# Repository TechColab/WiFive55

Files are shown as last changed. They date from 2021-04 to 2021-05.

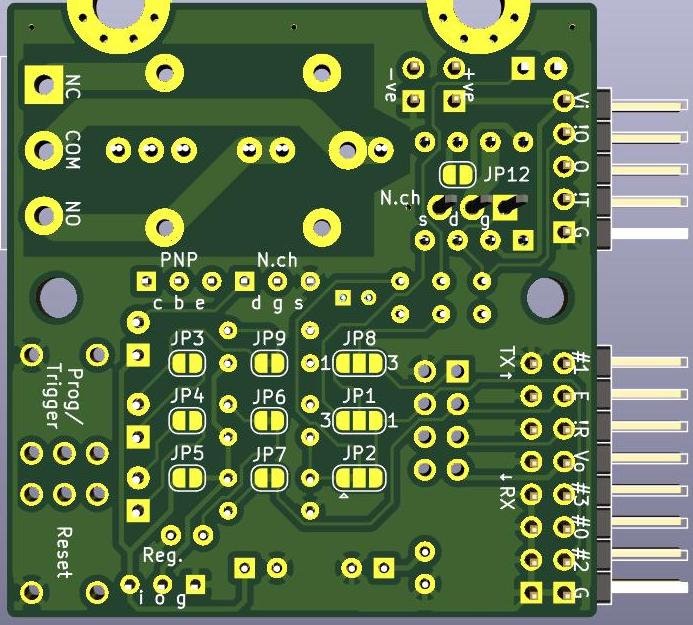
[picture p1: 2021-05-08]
KiCAD-THT/WiFive55-B.jpg

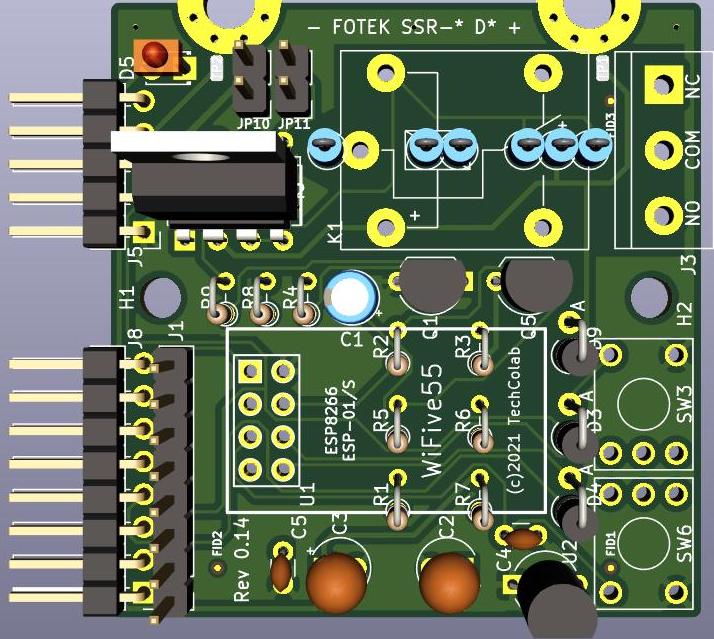
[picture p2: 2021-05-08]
KiCAD-THT/WiFive55-F.jpg

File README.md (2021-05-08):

# WiFive55

https://hackaday.io/project/178964-wifive55

.. or see the PDF

### 2021-05-03
Moved opto-isolator slightly to move relay footprints enough to accomodate longer but cheap & popular Omron G3MB-202P.  
Moved Through-Hole-Technology version to new folder to differentiate from Surface-Mount-Technology version to follow.

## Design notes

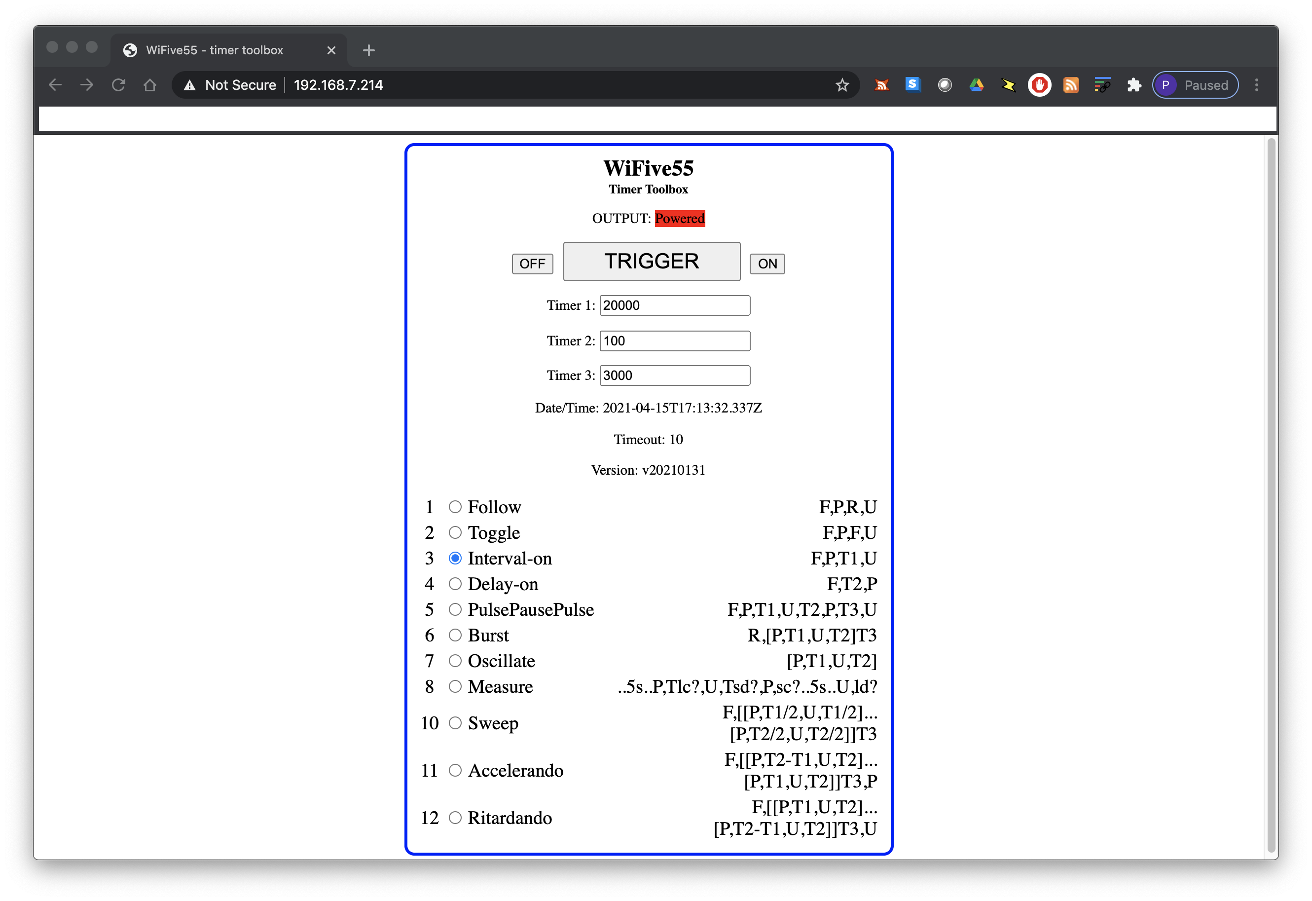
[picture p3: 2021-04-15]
Arduino/WiFive55-GUIalpha-running.png

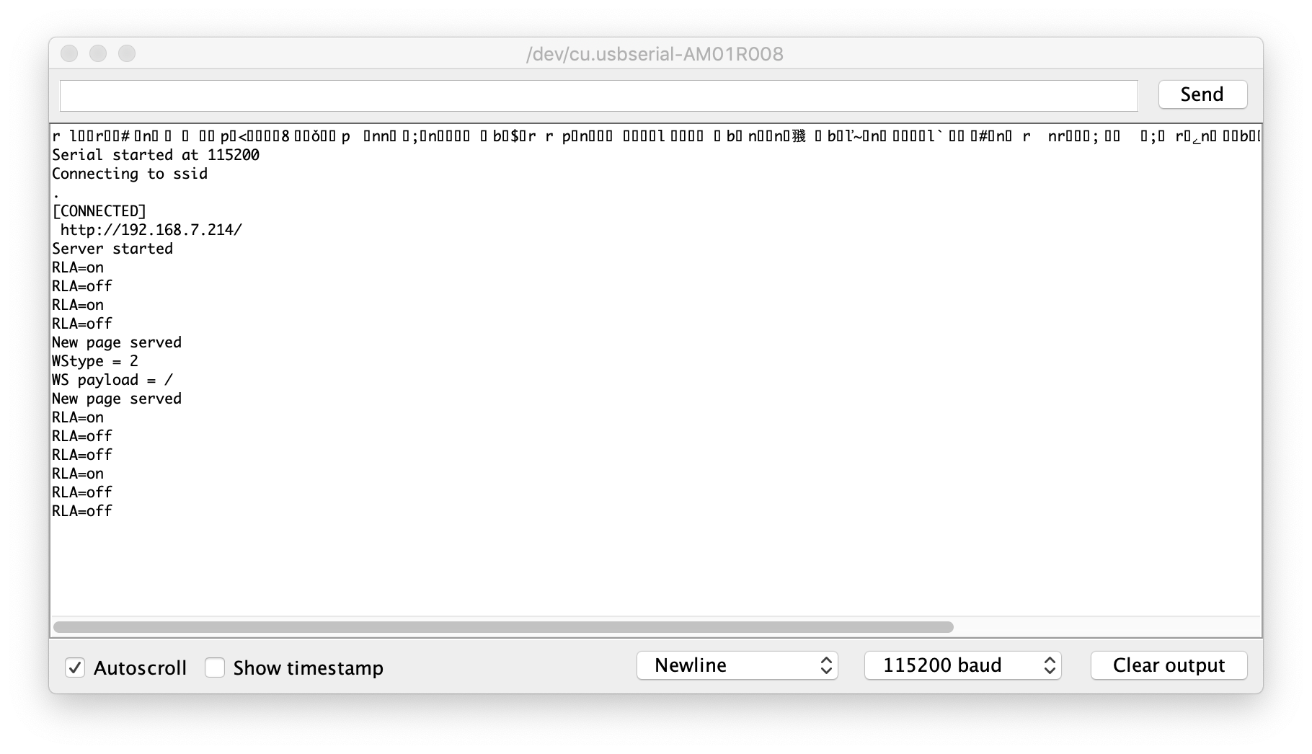
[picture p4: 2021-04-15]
Arduino/WiFive55-LOGalpha.png

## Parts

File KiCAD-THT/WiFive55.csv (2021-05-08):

Id | Designator | Package | Quantity | Designation | Supplier and ref
1 | , , , , , | TestPoint_Loop_D1.80mm_Drill1.0mm_Beaded | 6 | TestPoint_Loop_D1.80mm_Drill1.0mm_Beaded
2 | C3,C2 | CP_Radial_Tantal_D4.5mm_P2.50mm | 2 | 10
3 | C1 | CP_Radial_D4.0mm_P2.00mm | 1 | 4.7
4 | R4 | R_Axial_DIN0204_L3.6mm_D1.6mm_P2.54mm_Vertical | 1 | 200
5 | TP3 | MountingHole_4mm_Pad_Via | 1 | VIN+
6 | TP4 | MountingHole_4mm_Pad_Via | 1 | !OUT-
7 | TP2 | SolderWirePad_1x01_SMD_1x2mm | 1 | !OUT-
8 | TP1 | SolderWirePad_1x01_SMD_1x2mm | 1 | VIN+
9 | Q2 | TO-220-3_Vertical | 1 | IRF540N
10 | Q5 | TO-92_Inline_Wide | 1 | BC557
11 | Q1 | TO-92_Inline_Wide | 1 | BS170
12 | JP12 | SolderJumper-2_P1.3mm_Open_RoundedPad1.0x1.5mm | 1 | 6-pin
13 | JP10 | PinHeader_1x02_P2.54mm_Vertical | 1 | Vin
14 | JP11 | PinHeader_1x02_P2.54mm_Vertical | 1 | GND
15 | R1 | R_Axial_DIN0204_L3.6mm_D1.6mm_P2.54mm_Vertical | 1 | 51k
16 | R2,R3,R6,R7 | R_Axial_DIN0204_L3.6mm_D1.6mm_P2.54mm_Vertical | 4 | 10k
17 | R8 | R_Axial_DIN0204_L3.6mm_D1.6mm_P2.54mm_Vertical | 1 | 470
18 | R5 | R_Axial_DIN0204_L3.6mm_D1.6mm_P2.54mm_Vertical | 1 | 8k2
19 | R9 | R_Axial_DIN0204_L3.6mm_D1.6mm_P2.54mm_Vertical | 1 | *
20 | JP9 | SolderJumper-2_P1.3mm_Bridged_RoundedPad1.0x1.5mm | 1 | Prg
21 | JP7 | SolderJumper-2_P1.3mm_Bridged_RoundedPad1.0x1.5mm | 1 | Ena
22 | JP6 | SolderJumper-2_P1.3mm_Bridged_RoundedPad1.0x1.5mm | 1 | Rst
23 | FID3,FID2,FID1 | Fiducial_0.5mm_Mask1mm | 3 | Fiducial
24 | U2 | TO-92L_Inline_Wide | 1 | 3.3Vdc 1A reg
25 | JP4,JP3 | SolderJumper-2_P1.3mm_Open_RoundedPad1.0x1.5mm | 2 | Schottky bypass
26 | J1 | PinHeader_1x08_P2.54mm_Vertical | 1 | Grounds
27 | J8 | PinHeader_1x08_P2.54mm_Horizontal | 1 | Breadboard
28 | J5 | PinHeader_1x05_P2.54mm_Horizontal | 1 | 555-esque
29 | U1 | ESP-01 | 1 | ESP-01/S
30 | H2,H1 | MountingHole_3.2mm_M3 | 2 | MountingHole
31 | C5,C4 | C_Disc_D3.0mm_W1.6mm_P2.50mm | 2 | 0.1
32 | U5 | DIP-8_W7.62mm | 1 | TLP250
33 | JP2 | SolderJumper-3_P1.3mm_Bridged12_RoundedPad1.0x1.5mm | 1 | RC_bypass
34 | D5 | LED_D1.8mm_W3.3mm_H2.4mm | 1 | LED
35 | J3 | TerminalBlock_bornier-3_P5.08mm | 1 | Switched Output
36 | D9 | D_A-405_P2.54mm_Vertical_AnodeUp | 1 | 1N4148
37 | D4,D3 | D_A-405_P2.54mm_Vertical_AnodeUp | 2 | 1N5817 Schottky
38 | JP1 | SolderJumper-3_P1.3mm_Open_RoundedPad1.0x1.5mm_NumberLabels | 1 | H/L
39 | JP8 | SolderJumper-3_P1.3mm_Open_RoundedPad1.0x1.5mm_NumberLabels | 1 | S/-
40 | JP5 | SolderJumper-2_P1.3mm_Open_RoundedPad1.0x1.5mm | 1 | Reg?
41 | SW6 | KSA_Tactile_SPST | 1 | RST
42 | SW3 | KSA_Tactile_SPST | 1 | PRG
43 | K1 | Relay_SPDT_Finder_36.11 | 1 | FINDER-36.11

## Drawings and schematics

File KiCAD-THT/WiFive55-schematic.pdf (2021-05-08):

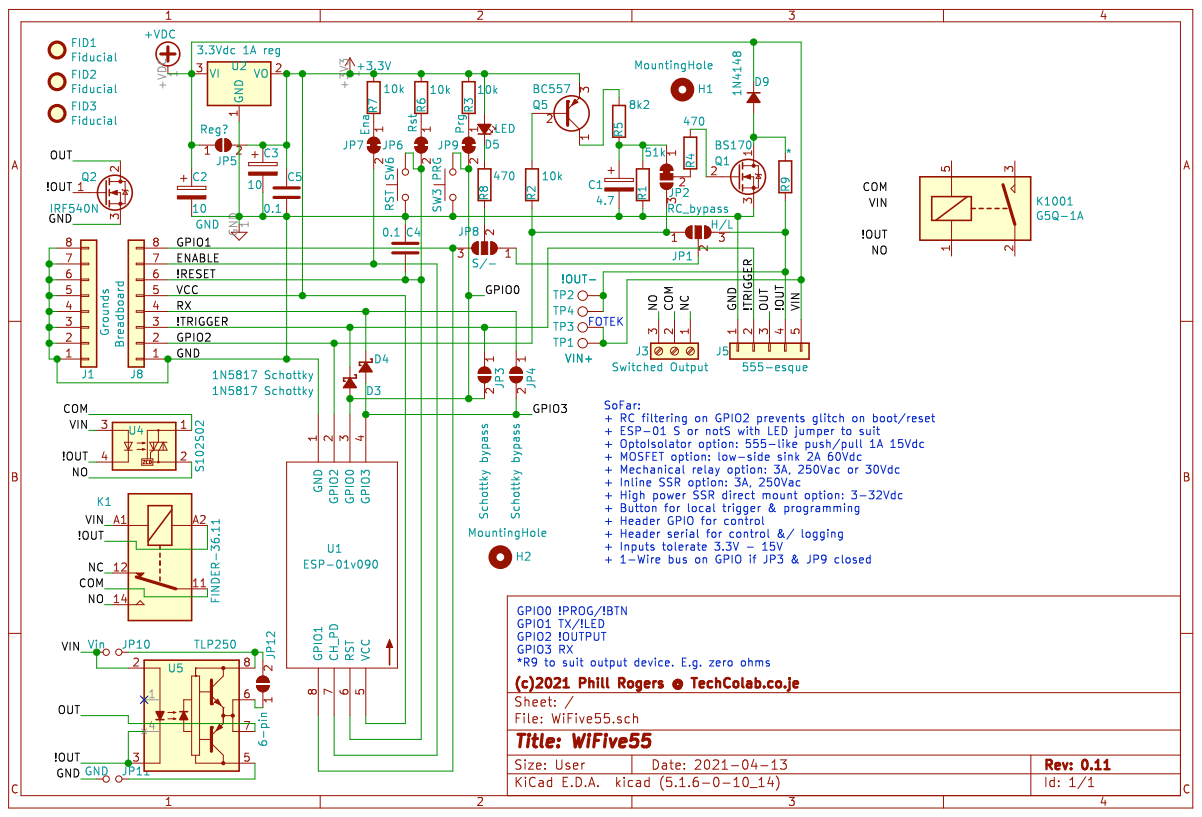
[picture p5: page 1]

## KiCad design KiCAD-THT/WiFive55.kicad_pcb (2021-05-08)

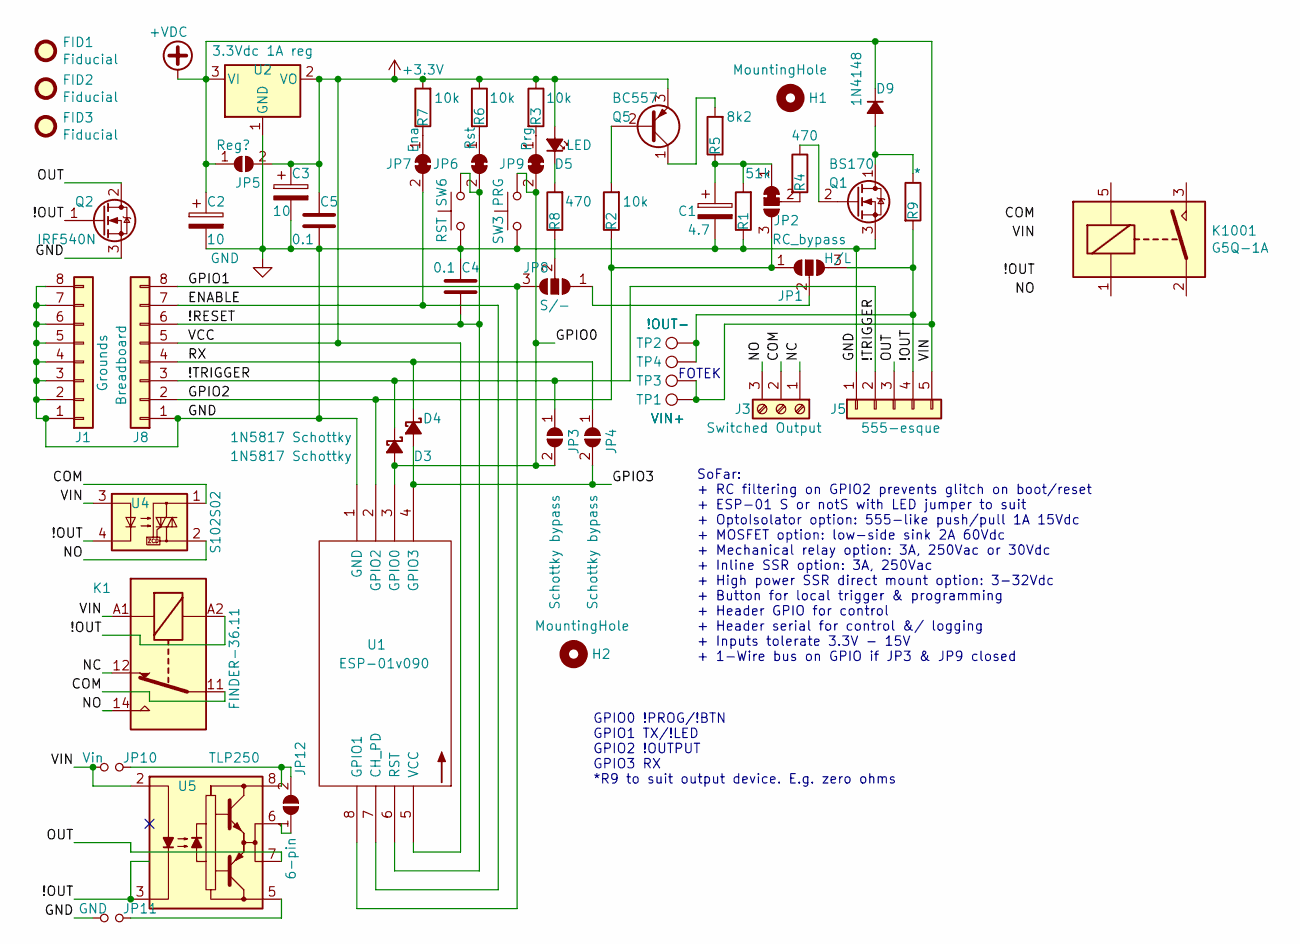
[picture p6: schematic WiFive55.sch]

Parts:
C1: 4.7; CP_Radial_D4.0mm_P2.00mm
C2, C3: 10; CP_Radial_Tantal_D4.5mm_P2.50mm
C4, C5: 0.1; C_Disc_D3.0mm_W1.6mm_P2.50mm
D3, D4: 1N5817 Schottky; D_A-405_P2.54mm_Vertical_AnodeUp
D5: LED; LED_D1.8mm_W3.3mm_H2.4mm
D9: 1N4148; D_A-405_P2.54mm_Vertical_AnodeUp
FID1, FID2, FID3: Fiducial; Fiducial_0.5mm_Mask1mm
H1, H2: MountingHole; MountingHole_3.2mm_M3
J1: Grounds; PinHeader_1x08_P2.54mm_Vertical
J3: Switched Output; TerminalBlock_bornier-3_P5.08mm
J5: 555-esque; PinHeader_1x05_P2.54mm_Horizontal
J8: Breadboard; PinHeader_1x08_P2.54mm_Horizontal
JP1: H/L; SolderJumper-3_P1.3mm_Open_RoundedPad1.0x1.5mm_NumberLabels
JP2: RC_bypass; SolderJumper-3_P1.3mm_Bridged12_RoundedPad1.0x1.5mm
JP3, JP4: Schottky bypass; SolderJumper-2_P1.3mm_Open_RoundedPad1.0x1.5mm
JP5: Reg?; SolderJumper-2_P1.3mm_Open_RoundedPad1.0x1.5mm
JP6: Rst; SolderJumper-2_P1.3mm_Bridged_RoundedPad1.0x1.5mm
JP7: Ena; SolderJumper-2_P1.3mm_Bridged_RoundedPad1.0x1.5mm
JP8: S/-; SolderJumper-3_P1.3mm_Open_RoundedPad1.0x1.5mm_NumberLabels
JP9: Prg; SolderJumper-2_P1.3mm_Bridged_RoundedPad1.0x1.5mm
JP10: Vin; PinHeader_1x02_P2.54mm_Vertical
JP11: GND; PinHeader_1x02_P2.54mm_Vertical
JP12: 6-pin; SolderJumper-2_P1.3mm_Open_RoundedPad1.0x1.5mm
K1: FINDER-36.11; Relay_SPDT_Finder_36.11
K1001: G5Q-1A; Relay_SPST_TE_PCN-1xxD3MHZ
Q1: BS170; TO-92_Inline_Wide
Q2: IRF540N; TO-220-3_Vertical
Q5: BC557; TO-92_Inline_Wide
R1: 51k; R_Axial_DIN0204_L3.6mm_D1.6mm_P2.54mm_Vertical
R2, R3, R6, R7: 10k; R_Axial_DIN0204_L3.6mm_D1.6mm_P2.54mm_Vertical
R4, R8: 470; R_Axial_DIN0204_L3.6mm_D1.6mm_P2.54mm_Vertical
R5: 8k2; R_Axial_DIN0204_L3.6mm_D1.6mm_P2.54mm_Vertical
R9: *; R_Axial_DIN0204_L3.6mm_D1.6mm_P2.54mm_Vertical
SW3: PRG; KSA_Tactile_SPST
SW6: RST; KSA_Tactile_SPST
TP1: VIN+; SolderWirePad_1x01_SMD_1x2mm
TP2: !OUT-; SolderWirePad_1x01_SMD_1x2mm
TP3: VIN+; MountingHole_4mm_Pad_Via
TP4: !OUT-; MountingHole_4mm_Pad_Via
U1: ESP-01v090
U2: 3.3Vdc 1A reg; TO-92L_Inline_Wide
U4: S102S02; SIP4_Sharp-SSR_P7.62mm_Straight
U5: TLP250; DIP-8_W7.62mm

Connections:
+3V3: C3.1, C5.1, D5.2 (A), J8.5, JP5.2 (B), Q5.3 (E), R3.1, R6.1, R7.2, U1.5 (VCC), U2.2 (VO)
+VDC: C2.1, D9.1 (K), J5.5, JP5.1 (A), JP10.1, K1.A1, TP1.1, TP3.1, U2.3 (VI), U4.3, U5.2 (A)
/!OUT: J5.4, JP1.3 (B), K1.A2, Q2.1 (G), R9.2, TP2.1, TP4.1, U4.4, U5.3 (C), U5.4 (NC)
/!RESET: C4.2, J8.6, JP6.2 (B), SW6.2, U1.6 (RST)
/!TRIGGER: D3.1 (K), J5.2, J8.3, JP3.1 (A)
/COM: J3.2, K1.11, U4.1
/ENABLE: J8.7, JP7.2 (B), U1.7 (CH_PD)
/GPIO0: D3.2 (A), JP3.2 (B), JP9.2 (B), SW3.1, U1.3 (GPIO0)
/GPIO1: J8.8, JP8.3 (B), U1.8 (GPIO1)
/GPIO2: J8.2, JP1.1 (A), JP2.3 (B), R2.1, U1.2 (GPIO2)
/GPIO3: D4.2 (A), JP4.2 (B), U1.4 (GPIO3)
/NC: J3.1, K1.12
/NO: J3.3, K1.14, U4.2
/OUT: J5.3, Q2.2 (D), U5.7 (VO)
/RX: D4.1 (K), J8.4, JP4.1 (A)
GND: C1.2, C2.2, C3.2, C4.1, C5.2, J1.1, J1.2, J1.3, J1.4, J1.5, J1.6, J1.7, J1.8, J5.1, J8.1, JP11.1, Q1.3 (S), Q2.3 (S), R1.1, SW3.2, SW6.1, U1.1 (GND), U2.1 (GND)
unnamed: C1.1, JP2.1 (A), R1.2, R5.1
unnamed: D5.1 (K), R8.2
unnamed: D9.2 (A), Q1.1 (D), R9.1
unnamed: JP1.2 (C), JP8.1 (A)
unnamed: JP2.2 (C), R4.2
unnamed: JP6.1 (A), R6.2
unnamed: JP7.1 (A), R7.1
unnamed: JP8.2 (C), R8.1
unnamed: JP9.1 (A), R3.2
unnamed: JP10.2, JP12.2 (B), U5.8 (VCC)
unnamed: JP11.2, U5.5 (VEE)
unnamed: JP12.1 (A), U5.6 (VO)
unnamed: Q1.2 (G), R4.1
unnamed: Q5.1 (C), R5.2
unnamed: Q5.2 (B), R2.2

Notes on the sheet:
GPIO0 !PROG/!BTN GPIO1 TX/!LED GPIO2 !OUTPUT GPIO3 RX *R9 to suit output device. E.g. zero ohms
SoFar: + RC filtering on GPIO2 prevents glitch on boot/reset + ESP-01 S or notS with LED jumper to suit + OptoIsolator option: 555-like push/pull 1A 15Vdc + MOSFET option: low-side sink 2A 60Vdc + Mechanical relay option: 3A, 250Vac or 30Vdc + Inline SSR option: 3A, 250Vac + High power SSR direct m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
FOTEK

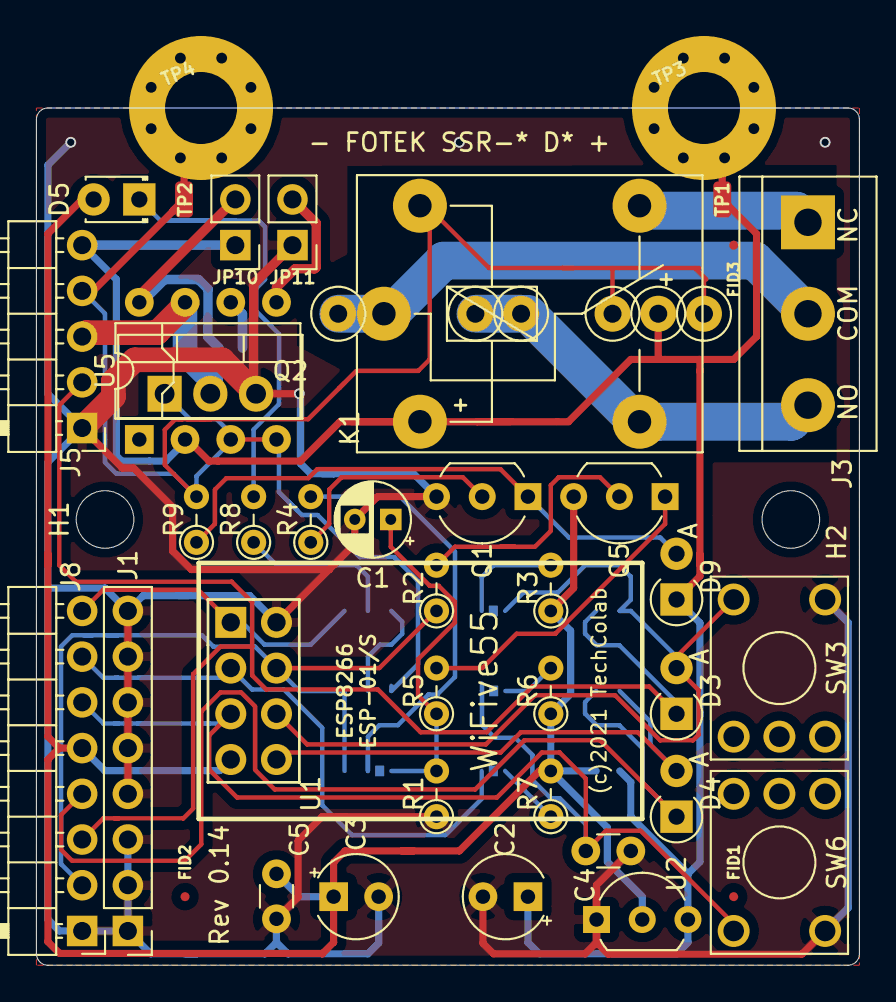
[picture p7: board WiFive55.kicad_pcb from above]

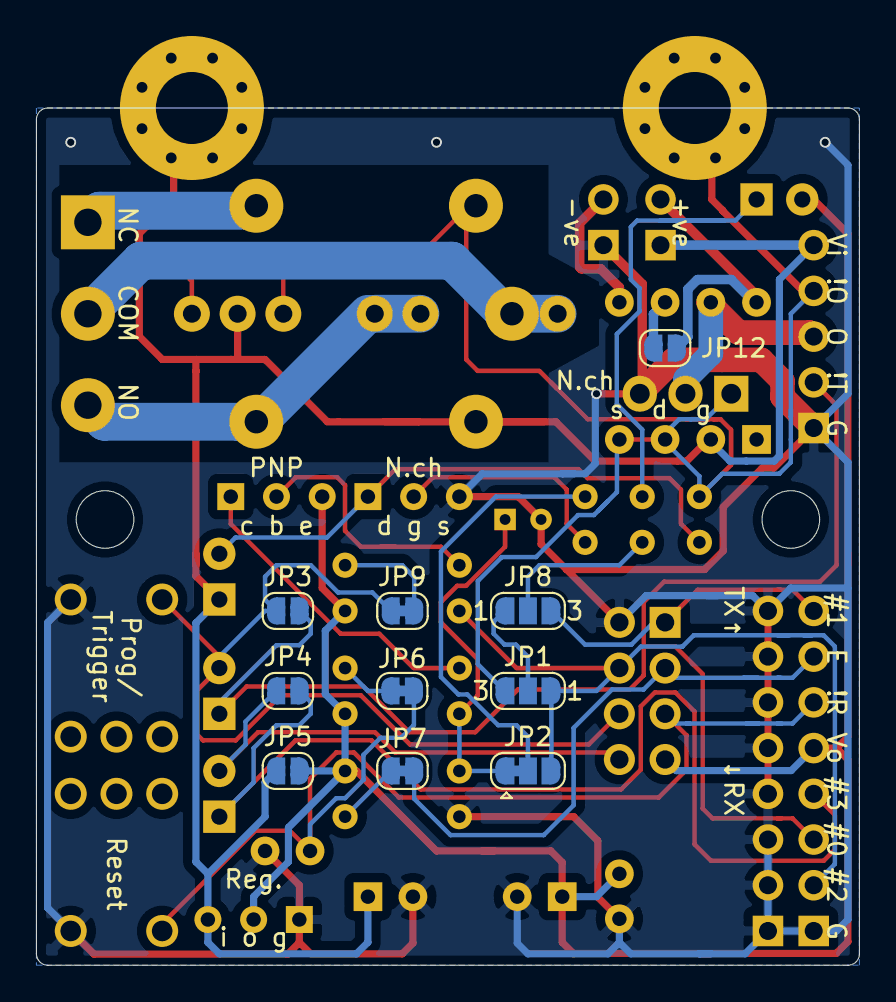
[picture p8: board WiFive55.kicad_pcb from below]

Board: 2 copper layers, 45.7 x 47.6 mm, 58 parts (10 on the bottom side), 31 nets.

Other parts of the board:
 : TestPoint_Loop_D1.80mm_Drill1.0mm_Beaded
 #2,  #3,  #4,  #5,  #6: TestPoint_Loop_D1.80mm_Drill1.0mm_Beaded

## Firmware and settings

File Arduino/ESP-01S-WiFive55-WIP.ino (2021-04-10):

/*
    (C) Copyright 2021 Phill Rogers.

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
    You should have received a copy of the GNU General Public License
    along with this program.  If not, see <https://www.gnu.org/licenses/>.
 */

/*
 * 2021-01-21  Phill
 * Notes:
 * KeyWords for initials: Rising/Falling, High/Low, Charge/Discharge, Powered/Unpowered
 * Sketch: ESP-01S_WiFive55_WebSock-IO to be run on an ESP-01/S
 * 
 * SoFar:
 * RLA is asctive low.  BTN is active low.
 * rename pin/functions: INPUT & OUTPUT, TRIGGER & OUTPUT, BUTTON & RELAY, BTN & RLA ? 
 * consistent order & case: object_attribute - btn_pin, btn_state, checkSwitch -> btn_check
 * Tidy white space
 * Get Date/Time from browser "Wed Jan 13 2021 20:10:23 GMT+0000 (Greenwich Mean Time)"
 * Date in ISO
 * Start up state should be off.
 * No need for Bounce2 lib as the hardware delay does de-bounce.
 * throb builtin LED at boot to show when to press for config.
 * Two modes but not yet selecting
 * Get mode from device.
 * Send mode request to device.  
 * mode of operation selection by GUI
 * time-delay mode: hard-coded 2s falling edge trigger
 * time-interval mode with editable mS
 * oscillate mode (as fast as possible)
 * burst mode, using rising edge
 * pulse-pause-pulse
 * Version in GUI
 * add numbers to table to show mode number when selecting by button.
 * add place-holder for Sweep, fade-on, fade-off.  fix startup timing, tidy code.
 * on GUI start, get mode from dev to gui
 * add count-down for long timers
 * add ON & OFF button for instant action, clearing current timeouts
 * Measure, with time-out in case RLA not wored to BTN
 * Config mode if btn was changed & returned during the throb. Allows for Normally Closed builds.
 * show responce times in GUI atr start.
 * 
 * ToDo:
 * version not showing on iOS but OK in Chrome.
 * How to get touch interface to not select nearby text when trigger button is held?
 * d & l mode for rising edge?
 * on GUI start, get date from gui to dev
 * Get Date/Time to device at start up
 * Browser to show time of last press?
 * mode of operation selection by BTN
 * SPIFFS lib to save settings, log
 * image files for web service?
 * OTA update?
 */

#include <ESP8266WiFi.h>
#include <WebSocketsServer.h>
#define margin 1.1
WiFiServer server(80);
WebSocketsServer webSocket = WebSocketsServer(81);
char ssid[] = "F7SHC_optout" ;
char pass[] = "jzyfjxxi" ;
byte led_pin = 1; // shared with serial TX
byte btn_pin = 0;
byte rla_pin = 2;
char mo_now[] = "T";
boolean btn_sim = HIGH;
boolean btn_state = HIGH;
boolean rla_state = HIGH;
boolean btn_prev = HIGH;
char *ptr, buf[256];
boolean mo_b_prev = HIGH;
/* following taken exactly from auto measure function */
unsigned long long_charge = 45L;
unsigned long short_discharge = 8L;
unsigned long short_charge = 7L;
unsigned long long_discharge = 98L;
unsigned long countdown_prev = 0L;
unsigned long time_last_sent_on = 0L;
unsigned long time_last_sent_off = 0L;
unsigned long time_last_here = 0L;
unsigned long time_out1 = 0L;
unsigned long time_out2 = 0L;
unsigned long time_out3 = 0L;
unsigned long time_delay1 = 200L;
unsigned long time_delay2 = 600L;
unsigned long time_delay3 = 3000L;

String index_htm = R"=index=(
<!DOCTYPE html><html><head>
  <meta name='viewport' content='width=device-width, initial-scale=1.0'/>
  <meta charset='utf-8'/>
  <style>
    body     { font-size:120%; -webkit-touch-callout: none; -webkit-user-select: none; }
    #main    { display:table; width:320px; margin:auto; padding:10px 10px 10px 10px; 
               border:3px solid blue; border-radius:10px; text-align:center; } 
    #BTN_TRG { width:180px; height:40px; font-size:110%; }
    p        { font-size:75%; }
    .c3      { text-align:left; }
    .c4      { text-align:right; padding-left: 18px; }
    h3       { padding: 0px; margin: 0px; }
    h6       { padding: 0px; margin: 0px; }
    table    { margin-left: auto; margin-right: auto; }
    button   { -webkit-touch-callout: none; -webkit-user-select: none; }
  </style>
  <title>WiFive55 - timer toolbox</title>
</head>
<body><div id='main'><h3>WiFive55</h3><h6>Timer Toolbox</h6><div id='content'>
  <p>OUTPUT:&nbsp;<span id='RLA_status'>Unpowered</span></p>
  <button name="RST" id='rst_off' class='button' onclick='rst(this);' >OFF</button>&nbsp;
  <button id='BTN_TRG' class='button'>TRIGGER</button>&nbsp;
  <button name="RST" id='rst_on' class='button' onclick='rst(this);' >ON</button><br/>
  <p>Timer 1:&nbsp;<input type='number' id='t1' name='td' min="0" value="" onchange='td_req(this);'></p>
  <p>Timer 2:&nbsp;<input type='number' id='t2' name='td' min="0" value="" onchange='td_req(this);'></p>
  <p>Timer 3:&nbsp;<input type='number' id='t3' name='td' min="0" value="" onchange='td_req(this);'></p>
  <p>Date/Time: <span id='dt'>---</span></p>
  <p>Timeout: <span id='rd'>---</span></p>
  <p>Version: <span id='vn'>---</span></p>
  <table>
    <tr><td>1</td><td><input type='radio' name='mo_sel' onclick='mo_req(this);' id='mo_F' value='F'></td>
      <td class='c3'>Follow</td><td class='c4'>F,P,R,U</td></tr>
    <tr><td>2</td><td><input type='radio' name='mo_sel' onclick='mo_req(this);' id='mo_T' value='T'></td>
      <td class='c3'>Toggle</td><td class='c4'>F,P,F,U</td></tr>
    <tr><td>3</td><td><input type='radio' name='mo_sel' onclick='mo_req(this);' id='mo_I' value='I'></td>
      <td class='c3'>Interval-on</td><td class='c4'>F,P,T1,U</td></tr>
    <tr><td>4</td><td><input type='radio' name='mo_sel' onclick='mo_req(this);' id='mo_D' value='D'></td>
      <td class='c3'>Delay-on</td><td class='c4'>F,T2,P</td></tr>
    <tr><td>5</td><td><input type='radio' name='mo_sel' onclick='mo_req(this);' id='mo_P' value='P'></td>
      <td class='c3'>PulsePausePulse</td><td class='c4'>F,P,T1,U,T2,P,T3,U</td></tr>
    <tr><td>6</td><td><input type='radio' name='mo_sel' onclick='mo_req(this);' id='mo_B' value='B'></td>
      <td class='c3'>Burst</td><td class='c4'>R,[P,T1,U,T2]T3</td></tr>
    <tr><td>7</td><td><input type='radio' name='mo_sel' onclick='mo_req(this);' id='mo_O' value='O'></td>
      <td class='c3'>Oscillate</td><td class='c4'>[P,T1,U,T2]</td></tr>
    <tr><td>8</td><td><input type='radio' name='mo_sel' onclick='mo_req(this);' id='mo_M' value='M'></td>
      <td class='c3'>Measure</td><td class='c4'>..5s..P,Tlc?,U,Tsd?,P,sc?..5s..U,ld?</td></tr>
    <tr><td>10</td><td><input type='radio' name='mo_sel' onclick='mo_req(this);' id='mo_S' value='S'></td>
      <td class='c3'>Sweep</td><td class='c4'>F,[[P,T1/2,U,T1/2]...<br/>[P,T2/2,U,T2/2]]T3</td></tr>
    <tr><td>11</td><td><input type='radio' name='mo_sel' onclick='mo_req(this);' id='mo_A' value='A'></td>
      <td class='c3'>Accelerando</td><td class='c4'>F,[[P,T2-T1,U,T2]...<br/>[P,T1,U,T2]]T3,P</td></tr>
    <tr><td>12</td><td><input type='radio' name='mo_sel' onclick='mo_req(this);' id='mo_R' value='R'></td>
      <td class='c3'>Ritardando</td><td class='c4'>F,[[P,T1,U,T2]...<br/>[P,T2-T1,U,T2]]T3,U</td></tr>
  </table>
</div></div></body>
<script>
var Socket;
var currentTime = new Date();
function sendText(data) { Socket.send(data); }
document.getElementById('dt').innerHTML = currentTime.toISOString(); // sendText(currentTime);
function init() {
  Socket = new WebSocket('ws://' + window.location.hostname + ':81/');
  Socket.onmessage = function(event) { processReceivedCommand(event); };
}
function processReceivedCommand(evt) {
  if(evt.data === '1') {
    document.getElementById('RLA_status').innerHTML = 'Unpowered';
    document.getElementById('RLA_status').style.backgroundColor = 'LightGreen';
  } else
  if(evt.data === '0') {
    document.getElementById('RLA_status').innerHTML = 'Powered';
    document.getElementById('RLA_status').style.backgroundColor = 'Red';
  } else
  if(evt.data[0] == 'v') {
    document.getElementById('vn').innerHTML = evt.data;
  } else
  if(evt.data[0] == '@') {
    num = evt.data.substring(4);
    if(evt.data[2]=='1'){document.getElementById('t1').value=num}
    if(evt.data[2]=='2'){document.getElementById('t2').value=num}
    if(evt.data[2]=='3'){document.getElementById('t3').value=num}
  }
  else
  if(evt.data[0] == ' ') {
    if(evt.data[1] == ' ') { document.getElementById('rd').innerHTML = ''; }
    else { document.getElementById('rd').innerHTML = evt.data; }
  }  
  else
  if((evt.data[0] >= 'A') && (evt.data[0] <= 'Z')) {
    document.getElementById('mo_'+evt.data[0]).checked = true;
  }
}
document.getElementById('BTN_TRG').addEventListener('mousedown', btn_down);
function btn_down() { sendText('0'); }
document.getElementById('BTN_TRG').addEventListener('mouseup', btn_up);
function btn_up() { sendText('1'); }
function mo_req(mo_radio) { sendText(mo_radio.value);}
function rst(rst_btn) { sendText(rst_btn.id);}
function td_req(td_num) { sendText('@'+td_num.id+' '+td_num.value);}
window.onload = function(e) { init(); }
</script>
</html>
)=index=";
String header = "HTTP/1.1 200 OK\r\nContent-Type: text/html\r\n\r\n";

void webSocketEvent(byte num, WStype_t type, uint8_t * payload, size_t length) {
  if(type == WStype_TEXT) {
    if ( (payload[0] >= 'A') && (payload[0] <= 'Z') ) {
      mo_now[0] = payload[0];
      time_out1 = time_out2 = time_out3 = 0;
    }
    else if (payload[0] == '0') { btn_sim = LOW; }
    else if (payload[0] == '1') { btn_sim = HIGH; }
    else if (payload[0] == '@') {
      for(int i=4; i<length; i++) { buf[i-4] = (char)payload[i]; }
      if(payload[2] == '1') { sscanf(buf, "%lu", &time_delay1); }
      if(payload[2] == '2') { sscanf(buf, "%lu", &time_delay2); }
      if(payload[2] == '3') { sscanf(buf, "%lu", &time_delay3); }
      memset(buf, 0, sizeof(buf));
    }
    else if (payload[0] == 'r') {
      time_out1 = time_out2 = time_out3 = 0;
      if(payload[5] == 'n') { rla_on(); }
      if(payload[5] == 'f') { rla_off(); }
    }
  }
  else {
    Serial.print("WStype = "); Serial.println(type);
    Serial.print("WS payload = ");
    for(int i=0; i<length; i++) { Serial.print((char) payload[i]); }
    Serial.println();
  }
}

void rla_on() {
  unsigned long since=millis() - time_last_sent_off;
  rla_state = LOW;
  log("RLA=on");
  webSocket.broadcastTXT("0");
  if(since < short_discharge) {
    delay(short_charge - since);
  } else if(since < long_discharge) {
      delay(long_charge - since);
    }
  digitalWrite(rla_pin, LOW);
  time_last_sent_on = millis();
}
void rla_off() {
  unsigned long since=millis() - time_last_sent_off;
  rla_state = HIGH;
  log("RLA=off");
  webSocket.broadcastTXT("1");
  if(since < short_charge) {
    delay(short_discharge - since);
  } else if(since < long_charge) {
      delay(long_discharge - since);
    }
  digitalWrite(rla_pin, HIGH);
  time_last_sent_off = millis();
}
void log(char *msg) {
  Serial.println(msg);
}

boolean throb(int reps) {
#define BRIGHT    350     //max led intensity (1-500)
#define INHALE    1250    //Inhalation time in milliseconds.
#define PULSE     INHALE*1000/BRIGHT
#define REST      1000    //Rest Between Inhalations.
  boolean btn_pushed = false;
  boolean btn_before = btn_state;
  pinMode(led_pin, OUTPUT);
  for(; reps>0; reps--) {
    for (int i=1;i<BRIGHT;i++){     // ramp up, Inhalation:
      digitalWrite(led_pin, LOW);      // turn the LED on.
      delayMicroseconds(i*10);         // wait
      digitalWrite(led_pin, HIGH);     // turn the LED off.
      delayMicroseconds(PULSE-i*10);   // wait
      delay(0);                        // to prevent watchdog firing.
      if(digitalRead(btn_pin) != btn_before) { btn_pushed = true; }
    }
    for (int i=BRIGHT-1;i>0;i--){   // ramp down, Exhalation (half time):
      digitalWrite(led_pin, LOW);      // turn the LED on.
      delayMicroseconds(i*10);         // wait
      digitalWrite(led_pin, HIGH);     // turn the LED off.
      delayMicroseconds(PULSE-i*10);   // wait
      i--;
      if(digitalRead(btn_pin) != btn_before) { btn_pushed = true; }
      delay(0);                        // to prevent watchdog firing.
    }
    if(reps >1) { delay(REST); }       //take a rest...
  }
  pinMode(led_pin, INPUT);
 if(digitalRead(btn_pin) != btn_before) { btn_pushed = false; }
 return(btn_pushed);
}

void measure() {
  unsigned long start_time = 0L;
  unsigned long long_charge = 0L;
  unsigned long short_discharge = 0L;
  unsigned long short_charge = 0L;
  unsigned long final_time = 0L;
  unsigned long long_discharge = 0L;
  char *ptr;
  digitalWrite(rla_pin, HIGH);
  time_out3 = millis() + 5000; while(millis() < time_out3) { delay(10); }
  time_out3 = millis() + 2000;
  start_time = millis();
  digitalWrite(rla_pin, LOW);
  while(digitalRead(btn_pin) == HIGH) { delay(1); if(millis() >= time_out3) { break; } }
  long_charge = millis();
  digitalWrite(rla_pin, HIGH);
  delay(7);
  time_out3 = millis() + 2000;
  while(digitalRead(btn_pin) == LOW) { delay(1); if(millis() >= time_out3) { break; } }
  short_discharge = millis();
  digitalWrite(rla_pin, LOW);
  delay(7);
  time_out3 = millis() + 2000;
  while(digitalRead(btn_pin) == HIGH) { delay(1); if(millis() >= time_out3) { break; } }
  short_charge = millis();
  time_out3 = millis() + 5000; while(millis() < time_out3) { delay(10); }
  time_out3 = millis() + 2000;
  final_time = millis();
  digitalWrite(rla_pin, HIGH);
  while(digitalRead(btn_pin) == LOW) { delay(1); if(millis() >= time_out3) { break; } }
  long_discharge = millis();
  digitalWrite(rla_pin, HIGH);
  time_out3 = 0L;
  memset(buf, 0, sizeof(buf));
  ptr = buf + strlen(buf); sprintf(ptr, " lc:%04lu", long_charge - start_time );
  ptr = buf + strlen(buf); sprintf(ptr, " sd:%04lu", short_discharge - long_charge  );
  ptr = buf + strlen(buf); sprintf(ptr, " sc:%04lu", short_charge - short_discharge );
  ptr = buf + strlen(buf); sprintf(ptr, " ld:%04lu", long_discharge - final_time );
}

void setup() {
  pinMode(rla_pin, OUTPUT);
  digitalWrite(rla_pin, rla_state);
  pinMode(btn_pin, INPUT_PULLUP);
  memset(buf, 0, sizeof(buf));
  if(throb(2)) { mo_now[0] = 'C'; }
  Serial.begin(115200);
  log("\nSerial started at 115200");
  if( mo_now[0] == 'C') {
    log("Config was requested. Please reset.");
  } // Config

  // Connect to a WiFi network
  Serial.print(F("Connecting to ")); Serial.println("ssid");
  WiFi.begin(ssid,pass);
  // connection with timeout
  int count = 0; 
  while ( (WiFi.status() != WL_CONNECTED) && count < 17) {
    Serial.print("."); delay(500); count++;
  }
  if (WiFi.status() != WL_CONNECTED) {
    Serial.println(""); Serial.print("Failed to connect to "); Serial.println(ssid);
    while(1);
  }

  Serial.println("");
  Serial.println(F("[CONNECTED]")); Serial.print(" http://"); Serial.print(WiFi.localIP());
  Serial.println("/ ");
  server.begin();
  Serial.println("Server started");
  webSocket.begin();
  webSocket.onEvent(webSocketEvent);
  // cannot send websocket text til there is a client listening.

  long_charge = ceil(long_charge * margin);
  short_discharge = ceil(short_discharge * margin);
  short_charge = ceil(short_charge * margin);
  long_discharge = ceil(long_discharge * margin);
}

void loop() {
  btn_state = (btn_sim && digitalRead(btn_pin));
  action();
  if(time_out3 >= 1000) {
    unsigned long countdown = 1+ceil((time_out3-millis())/1000);
    if(countdown != countdown_prev) {
      sprintf(buf," %lu", countdown); webSocket.broadcastTXT(buf);
      countdown_prev = countdown;
    }
  }
  webSocket.loop();
  WiFiClient client = server.available(); // Check if a client has connected
  if (!client) { return; }
  client.flush();
  client.print( header );
  client.print( index_htm ); delay(100); // depends on page complexity >= 5
  sprintf(buf, "@t1 %lu", time_delay1); webSocket.broadcastTXT(buf); memset(buf, 0, sizeof(buf));
  sprintf(buf, "@t2 %lu", time_delay2); webSocket.broadcastTXT(buf); memset(buf, 0, sizeof(buf));
  sprintf(buf, "@t3 %lu", time_delay3); webSocket.broadcastTXT(buf); memset(buf, 0, sizeof(buf));
  ptr = buf + strlen(buf); sprintf(ptr, " lc:%04lu", long_charge );
  ptr = buf + strlen(buf); sprintf(ptr, " sd:%04lu", short_discharge );
  ptr = buf + strlen(buf); sprintf(ptr, " sc:%04lu", short_charge );
  ptr = buf + strlen(buf); sprintf(ptr, " ld:%04lu", long_discharge );
  webSocket.broadcastTXT(buf); memset(buf, 0, sizeof(buf));
  webSocket.broadcastTXT(mo_now); webSocket.broadcastTXT("v20210131");
  log("New page served");
}

void action() {
  if(btn_state != btn_prev) { // Edge
    if( mo_now[0] == 'F' ) {
      if( btn_state == LOW ) { rla_on(); } else { rla_off(); }
    } // Follow
    if(btn_state == LOW) { // Falling Edge
      if(mo_now[0] == 'T') {
        mo_b_prev = ! mo_b_prev;
        if( mo_b_prev == LOW ) { rla_on(); } else { rla_off(); }
      } // Toggle
      if(mo_now[0] == 'I') {
        rla_on();
        time_out3 = millis() + time_delay1;
        sprintf(buf," %lu", time_delay1/1000); webSocket.broadcastTXT(buf);
      } // Interval-on: F,P,T1,U
      if(mo_now[0] == 'D') {
        time_out3 = millis() + time_delay2;
        sprintf(buf," %lu", time_delay2/1000); webSocket.broadcastTXT(buf);
      } // Delay: F,T2,P
      if(mo_now[0] == 'P') {
        sprintf(buf," %lu", (time_delay1+time_delay2+time_delay3)/1000); webSocket.broadcastTXT(buf);
        rla_on(); delay(time_delay1);
        rla_off(); delay(time_delay2);
        rla_on(); delay(time_delay3);
        rla_off(); delay(0);
        webSocket.broadcastTXT("  ");
      } // PulsePausePulse: F,P,T1,U,T2,P,T3,U
      if(mo_now[0] == 'S') {
        time_out3 = millis() + time_delay3;
        time_out1 = time_delay1 / 2;
        time_out2 = abs((time_delay3 / (time_delay2 - time_delay1))/2) ;
        time_last_here = millis();
        sprintf(buf," %lu", time_delay3/1000); webSocket.broadcastTXT(buf); memset(buf, 0, sizeof(buf));
      } // Sweep F,[[P,T1,U,T1]..[P,T2,U,T2]]T3
    } else { // Rising Edge
      if( mo_now[0] == 'B' ) {
        sprintf(buf," %lu", time_delay3/1000); webSocket.broadcastTXT(buf); memset(buf, 0, sizeof(buf));
        unsigned int count = 0;
        time_out3 = millis() + time_delay3;
        while(millis() < time_out3) { count++;
          rla_on(); delay(time_delay1);
          rla_off(); delay(time_delay2);
        }
        time_out3 = 0L;
        sprintf(buf, " Count: %u", count);
        log(buf);
        webSocket.broadcastTXT(buf); memset(buf, 0, sizeof(buf));
      } // Burst:R,[P,T1,U,T2]T3
      if( mo_now[0] == 'A' ) {
        time_out3 = millis() + time_delay3;
        time_out2 = time_delay3 / 10;
        log("WIP A");
      } // Accelerando F,[[P,T2-T1,U,T2]...[P,T1,U,T2]]T3,P
      if( mo_now[0] == 'R' ) {
        log("NYI");
        rla_off();
      } // Ritardando F,[[P,T1,U,T2]...[P,T2-T1,U,T2]]T3,U
    }
    btn_prev = btn_state;
  }
  if(time_out3 > 0) { // Long Timed
    if(mo_now[0] == 'I') {
      if(millis() >= time_out3) { rla_off(); time_out3 = 0L; webSocket.broadcastTXT("  "); }
    } // Interval-on: F,P,T1,U
    if(mo_now[0] == 'D') {
      if(millis() >= time_out3) { rla_on(); time_out3 = 0L; webSocket.broadcastTXT("  "); }
    } // Delay-on: F,T2,P
    if(mo_now[0] == 'S') {
      if(millis() >= time_out3) { rla_off(); time_out3 = 0L; webSocket.broadcastTXT("  "); } else {
        if(millis() >= (time_last_here + time_out2) ) {
          if(time_delay1 > time_delay2) { time_out1-=time_out2; } else { time_out1+=time_out2; }
          time_last_here = millis();
        }
        if(millis() >= (time_last_here + time_out1) ) {
          if(rla_state == LOW) { rla_on(); } else { rla_off(); }
        }
      }
    }
    if(millis() >= time_out3) { rla_off(); time_out3 = 0L; webSocket.broadcastTXT("  "); } else {
      if(mo_now[0] == 'A') {
        int pc = (millis() - time_out3) / time_delay3; // time remaining as percentage of overall duration
        if(pc < 50) {
          time_out1 = (10 * (100 - pc))/pc ; // off time
          rla_on(); delay(10);
          rla_off(); delay(time_delay1);
        }
        if(pc = 50) {
          rla_on(); delay(50);
          rla_off(); delay(50);
        }
        if(pc > 50) {
          time_out1 = (10 * pc)/(100-pc) ; // on time
          rla_on(); delay(time_out1);
          rla_off(); delay(10);
        }
      }
    } // Accelerando F,[[P,T2-T1,U,T2]...[P,T1,U,T2]]T3,P
  } else { // Forever
    if( mo_now[0] == 'O' ) {
      rla_state = ! rla_state;
      if(rla_state == LOW) {
        rla_on(); delay(time_delay1);
      } else {
        rla_off(); delay(time_delay2);
      }
    } // Oscillate:[P,T1,U,T2]
    if( mo_now[0] == 'M' ) {
      log("Automatically measuring charge & discharge times.");
      measure(); log(buf); webSocket.broadcastTXT(buf);
    } // Measure ..5s..P,Tlc?,U,Tsd?,P,sc?..5s..U,ld?
  }
}

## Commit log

2021-04-15 update PCB for multiple SSR/RLA options
    [WiFive55-B_Cu.gbl, WiFive55-B_Mask.gbs, WiFive55-B_Paste.gbp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]
2021-04-15 cropped PCB renders
2021-04-15 cropped PCB B-render
2021-04-15 cropped PCB B render again
2021-04-15 PCB v0.12
    [WiFive55-B_Cu.gbl, WiFive55-B_Mask.gbs, WiFive55-B_Paste.gbp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]
2021-04-24 Rev. 0.13 PCB
    [WiFive55-B_Cu.gbl, WiFive55-B_Mask.gbs, WiFive55-B_Paste.gbp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]
2021-05-03 Space for Omron G3MB-202P
    [WiFive55-B_Cu.gbl, WiFive55-B_Mask.gbs, WiFive55-B_Paste.gbp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]
2021-05-08 update silks
    [WiFive55-B_Cu.gbl, WiFive55-B_Mask.gbs, WiFive55-B_Paste.gbp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]

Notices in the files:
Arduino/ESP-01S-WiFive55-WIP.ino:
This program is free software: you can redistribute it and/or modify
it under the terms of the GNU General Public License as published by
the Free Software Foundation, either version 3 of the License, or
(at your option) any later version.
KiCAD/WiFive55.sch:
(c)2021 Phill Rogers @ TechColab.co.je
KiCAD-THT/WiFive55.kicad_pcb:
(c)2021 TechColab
